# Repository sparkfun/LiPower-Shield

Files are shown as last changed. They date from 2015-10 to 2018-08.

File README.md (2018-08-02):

**NOTE:** *This product has been retired from our catalog. If you are looking for more up-to-date info, please check out some of these resources to see how other users are still hacking and improving on this product.*
* *[SparkFun Forum](https://forum.sparkfun.com/)*
* *[Comments Here on GitHub](https://github.com/sparkfun/LiPower-Shield/issues)*
* *[IRC Channel](https://www.sparkfun.com/news/263)*

SparkFun LiPower Shield
========================

LiPower Shield

[*SparkFun LiPower Shield (DEV-13158)*](https://www.sparkfun.com/products/13158)

This shield allows your Arduino to be powered from a 3.7V LiPo battery, while also charge and monitor the battery. 

Repository Contents
-------------------

* **/Hardware** - All Eagle design files (.brd, .sch)
* **/Production** - Production panel files (.brd)

Product Versions
----------------

* [DEV-13158](https://www.sparkfun.com/products/13158)- Version 1.1. Retired.
* [DEV-10711](https://www.sparkfun.com/products/retired/10711)- Version 1. Retired.

GitHub Version History
---------------
* [Version 1.1](https://github.com/sparkfun/LiPower-Shield/tree/V_1.1) - Latest hardware files. Retired..
* [Version 1](https://github.com/sparkfun/LiPower-Shield/tree/V_1) - Version 1. Retired. 

License Information
-------------------

This product is _**open source**_! 

Please review the LICENSE.md file for license information. 

If you have any questions or concerns on licensing, please contact techsupport@sparkfun.com.

Distributed as-is; no warranty is given.

- Your friends at SparkFun.

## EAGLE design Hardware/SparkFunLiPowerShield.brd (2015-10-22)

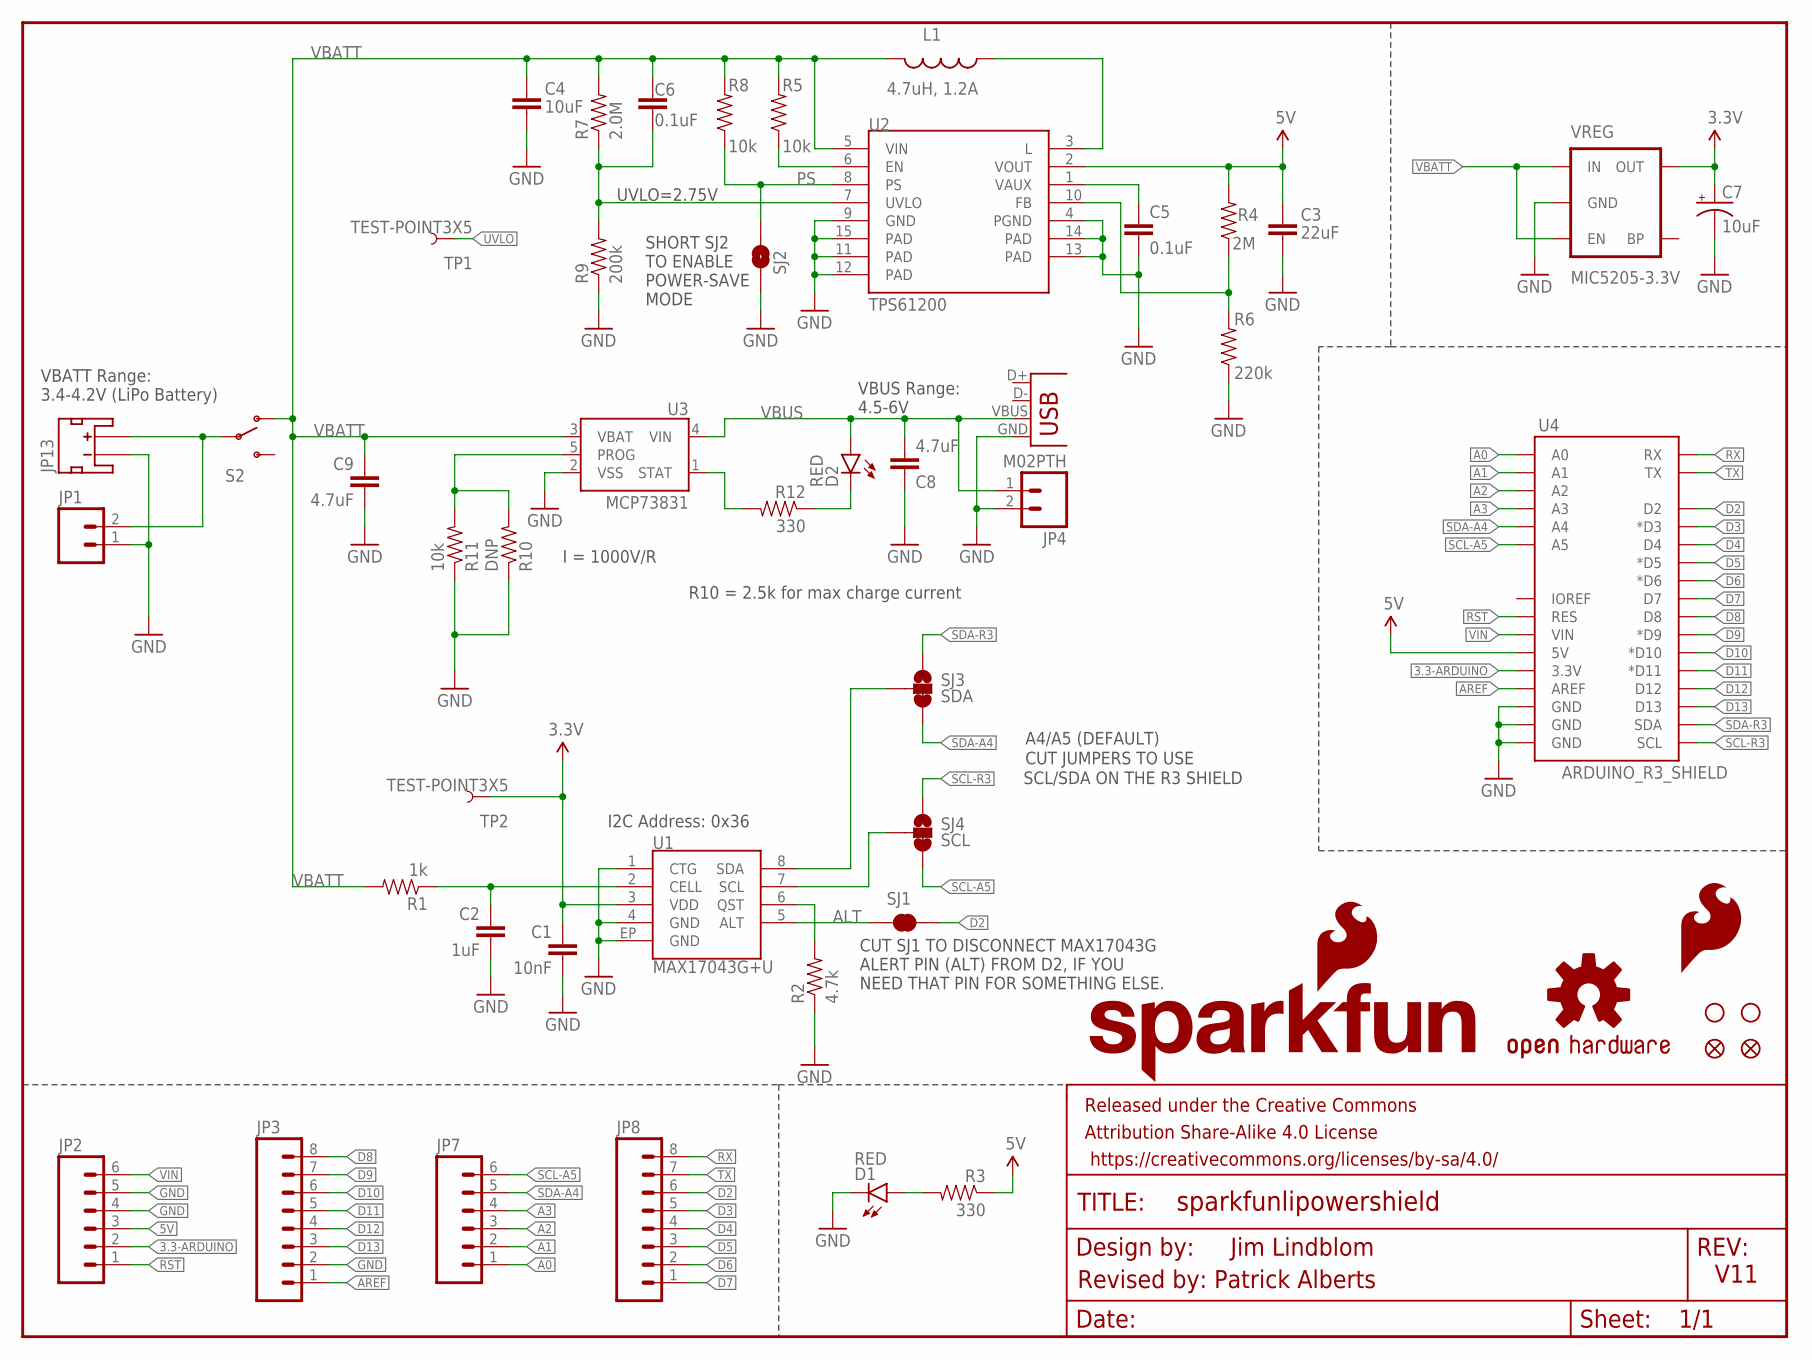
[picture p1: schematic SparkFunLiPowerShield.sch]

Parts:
C1: 10nF; 0603-CAP
C2: 1uF; 0603-CAP
C3: 22uF; 0805
C4: 10uF; 1206
C5, C6: 0.1uF; 0603-CAP
C7: 10uF; EIA3216
C8, C9: 4.7uF; 0603-CAP
D1, D2: RED; LED-0603
FID1, FID2: FIDUCIAL1X2; FIDUCIAL-1X2
FRAME1: FRAME-LETTER; CREATIVE_COMMONS
JP1: M021X02_NO_SILK; 1X02_NO_SILK
JP2, JP7: M06NO_SILK; 1X06_NO_SILK
JP3, JP8: M08NO_SILK; 1X08_NO_SILK
JP4: M02PTH; 1X02
JP9, JP10: STAND-OFFTIGHT; STAND-OFF-TIGHT
JP11: USBSMD; USB-MINIB
JP13: JST_2MM_MALE; JST-2-SMD
L1: 4.7uH, 1.2A; INDUCTOR_4.7UH
LOGO1: OSHW-LOGOS; OSHW-LOGO-S
LOGO2: SFE_LOGO_NAME_FLAME.2_INCH; SFE_LOGO_NAME_FLAME_.2
LOGO3: SFE_LOGO_FLAME.1_INCH; SFE_LOGO_FLAME_.1
R1: 1k; 0603-RES
R2: 4.7k; 0603-RES
R3, R12: 330; 0603-RES
R4: 2M; 0603-RES
R5, R8, R11: 10k; 0603-RES
R6: 220k; 0603-RES
R7: 2.0M; 0603-RES
R9: 200k; 0603-RES
R10: DNP; 1/6W-RES
S2: SWITCH-SPDT-SMD-A; SWITCH-SPST-SMD-A
SJ1: SOLDERJUMPERTRACE; SJ_2S-TRACE
SJ2: PS; SJ_2S-NO
SJ3: SDA; PAD-JUMPER-3-2OF3_NC_BY_TRACE_YES_SILK_FULL_BOX
SJ4: SCL; PAD-JUMPER-3-2OF3_NC_BY_TRACE_YES_SILK_FULL_BOX
TP1, TP2: TEST-POINT3X5; PAD.03X.05
U1: MAX17043G+U; TDFN-8
U2: TPS61200; QFN-10_PAD
U3: MCP73831; SOT23-5
U4: ARDUINO_R3_SHIELD; UNO_R3_SHIELD
VREG: MIC5205-3.3V; SOT23-5

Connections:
3.3-ARDUINO: JP2.2, U4.3.3V
3.3V: C1.1, C7.A (+), TP2.P$1, U1.3 (VDD), VREG.5 (OUT)
5V: C3.1, JP2.3, R3.1, R4.2, U2.2 (VOUT), U4.5V
A0: JP7.1, U4.A0
A1: JP7.2, U4.A1
A2: JP7.3, U4.A2
A3: JP7.4, U4.A3
ALT: SJ1.1, U1.5 (ALT)
AREF: JP3.1, U4.AREF
CELL: C2.1, R1.1, U1.2 (CELL)
D2: JP8.6, SJ1.2, U4.D2
D3: JP8.5, U4.D3 (*D3)
D4: JP8.4, U4.D4
D5: JP8.3, U4.D5 (*D5)
D6: JP8.2, U4.D6 (*D6)
D7: JP8.1, U4.D7
D8: JP3.8, U4.D8
D9: JP3.7, U4.D9 (*D9)
D10: JP3.6, U4.D10 (*D10)
D11: JP3.5, U4.D11 (*D11)
D12: JP3.4, U4.D12
D13: JP3.3, U4.D13
EN: R5.1, U2.6 (EN)
FB: R4.1, R6.2, U2.10 (FB)
GND: C1.2, C2.2, C3.2, C4.2, C5.2, C7.C (-), C8.1, C9.2, D1.C, JP1.1, JP2.4, JP2.5, JP3.2, JP4.2, JP11.GND, JP13.1 (-), R2.1, R6.1, R9.1, R10.1, R11.1, SJ2.1, U1.1 (CTG), U1.4 (GND), U1.EP (GND), U2.4 (PGND), U2.9 (GND), U2.11 (PAD), U2.12 (PAD), U2.13 (PAD), U2.14 (PAD), U2.15 (PAD), U3.2 (VSS), U4.GND@0 (GND), U4.GND@1 (GND), U4.GND@2 (GND), VREG.2 (GND)
unnamed: D1.A, R3.2
unnamed: L1.P$1 (1), U2.3 (L)
unnamed: C5.1, U2.1 (VAUX)
unnamed: D2.C, R12.1
unnamed: JP1.2, JP13.2 (+), S2.2
unnamed: SJ3.2, U1.8 (SDA)
PROG: R10.2, R11.2, U3.5 (PROG)
PS: R8.1, SJ2.2, U2.8 (PS)
QST: R2.2, U1.6 (QST)
RST: JP2.1, U4.RES
RX: JP8.8, U4.RX
SCL: SJ4.2, U1.7 (SCL)
SCL-A5: JP7.6, SJ4.3, U4.A5
SCL-R3: SJ4.1, U4.SCL
SDA-A4: JP7.5, SJ3.3, U4.A4
SDA-R3: SJ3.1, U4.SDA
STAT: R12.2, U3.1 (STAT)
TX: JP8.7, U4.TX
UVLO: C6.2, R7.1, R9.2, TP1.P$1, U2.7 (UVLO)
VBATT: C4.1, C6.1, C9.1, L1.P$2 (2), R1.2, R5.2, R7.2, R8.2, S2.1 (O), U2.5 (VIN), U3.3 (VBAT), VREG.1 (IN), VREG.3 (EN)
VBUS: C8.2, D2.A, JP4.1, JP11.VBUS, U3.4 (VIN)
VIN: JP2.6, U4.VIN

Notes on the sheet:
I = 1000V/R
R10 = 2.5k for max charge current
UVLO=2.75V
V11
Jim Lindblom
Revised by: Patrick Alberts
A4/A5 (DEFAULT)
CUT JUMPERS TO USE
SCL/SDA ON THE R3 SHIELD
SHORT SJ2 TO ENABLE POWER-SAVE MODE
CUT SJ1 TO DISCONNECT MAX17043G ALERT PIN (ALT) FROM D2, IF YOU NEED THAT PIN FOR SOMETHING ELSE.
I2C Address: 0x36
VBATT Range: 3.4-4.2V (LiPo Battery)
VBUS Range: 4.5-6V

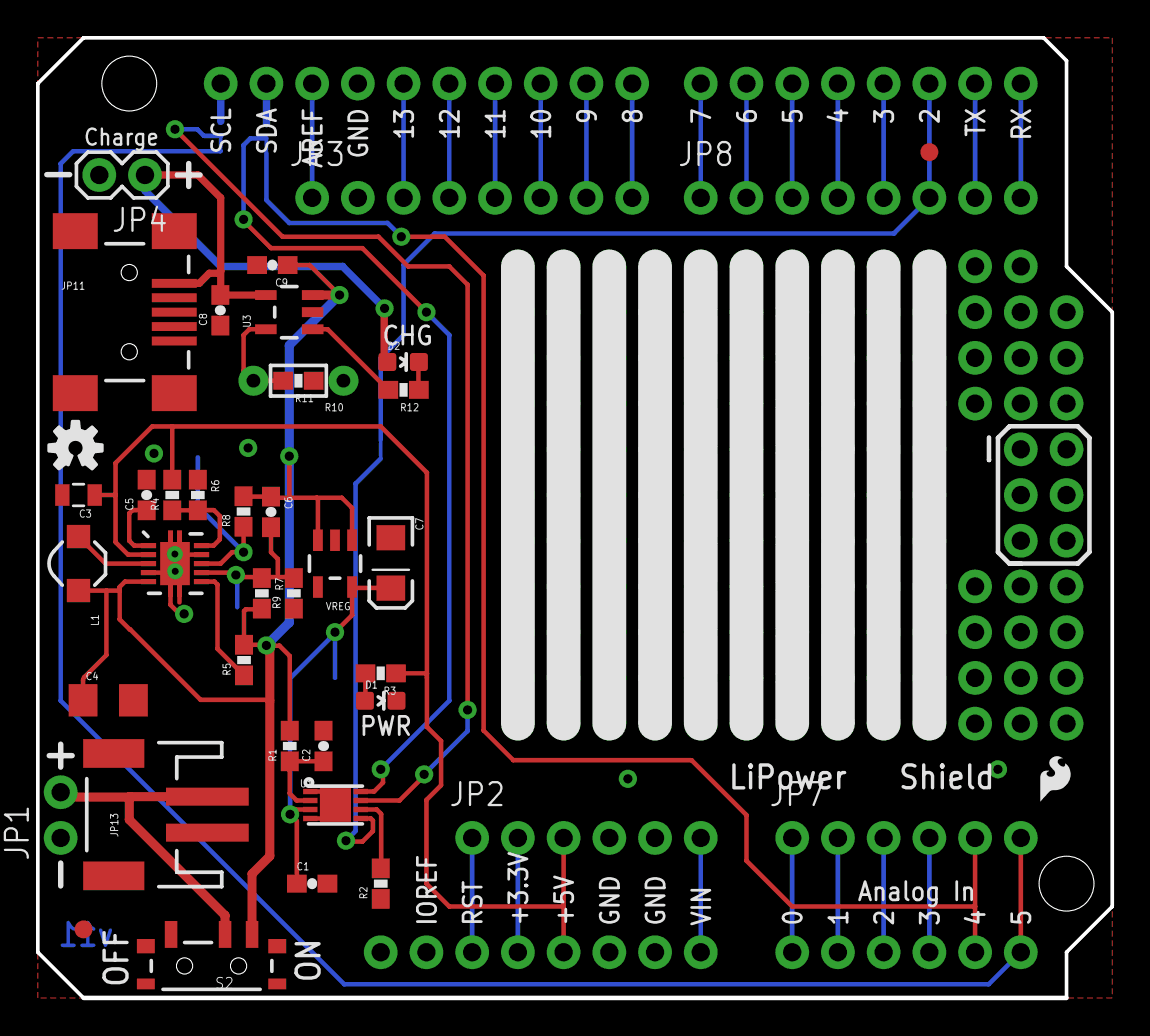
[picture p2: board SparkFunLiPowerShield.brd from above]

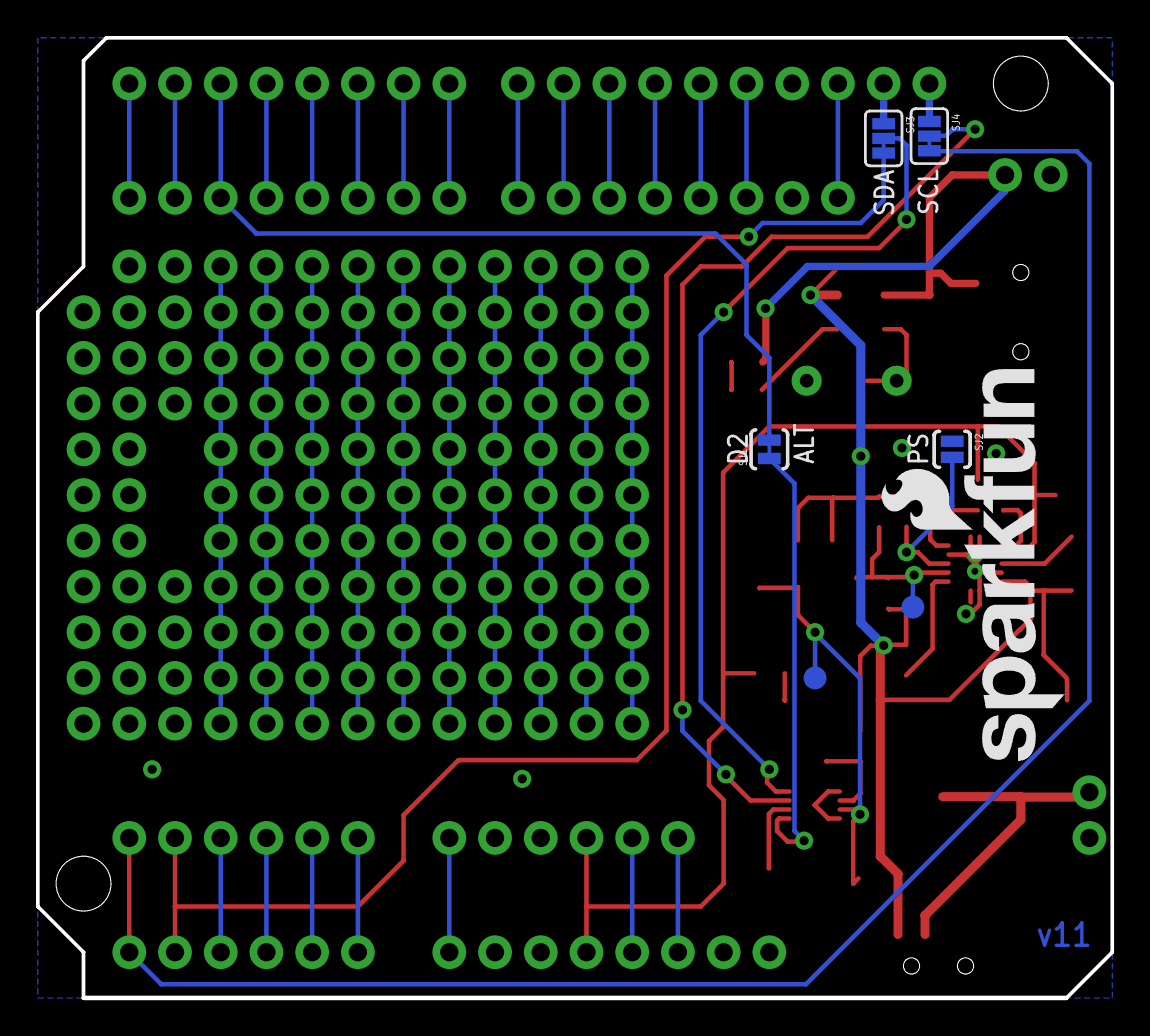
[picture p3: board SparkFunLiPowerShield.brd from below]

Board: 2 copper layers, 59.7 x 53.3 mm, 52 parts (7 on the bottom side), 47 nets.

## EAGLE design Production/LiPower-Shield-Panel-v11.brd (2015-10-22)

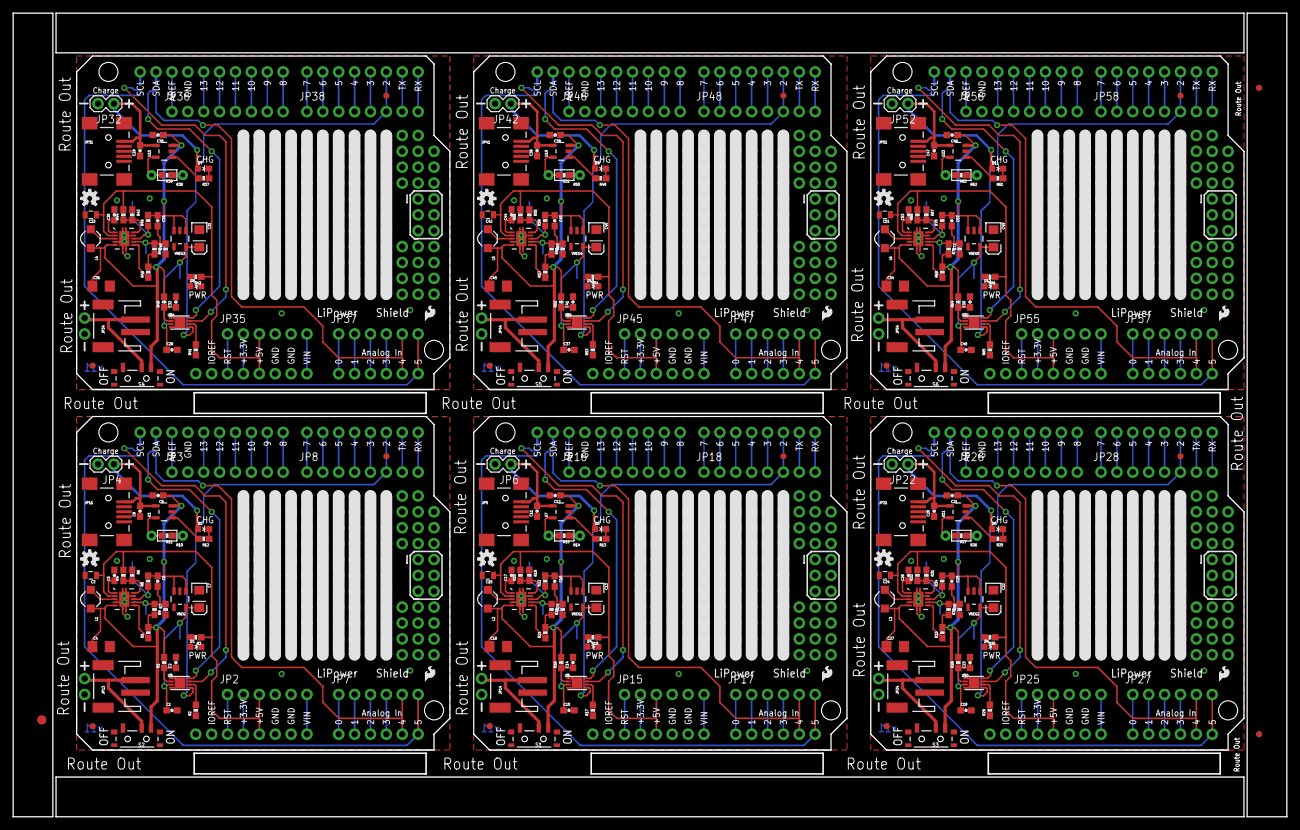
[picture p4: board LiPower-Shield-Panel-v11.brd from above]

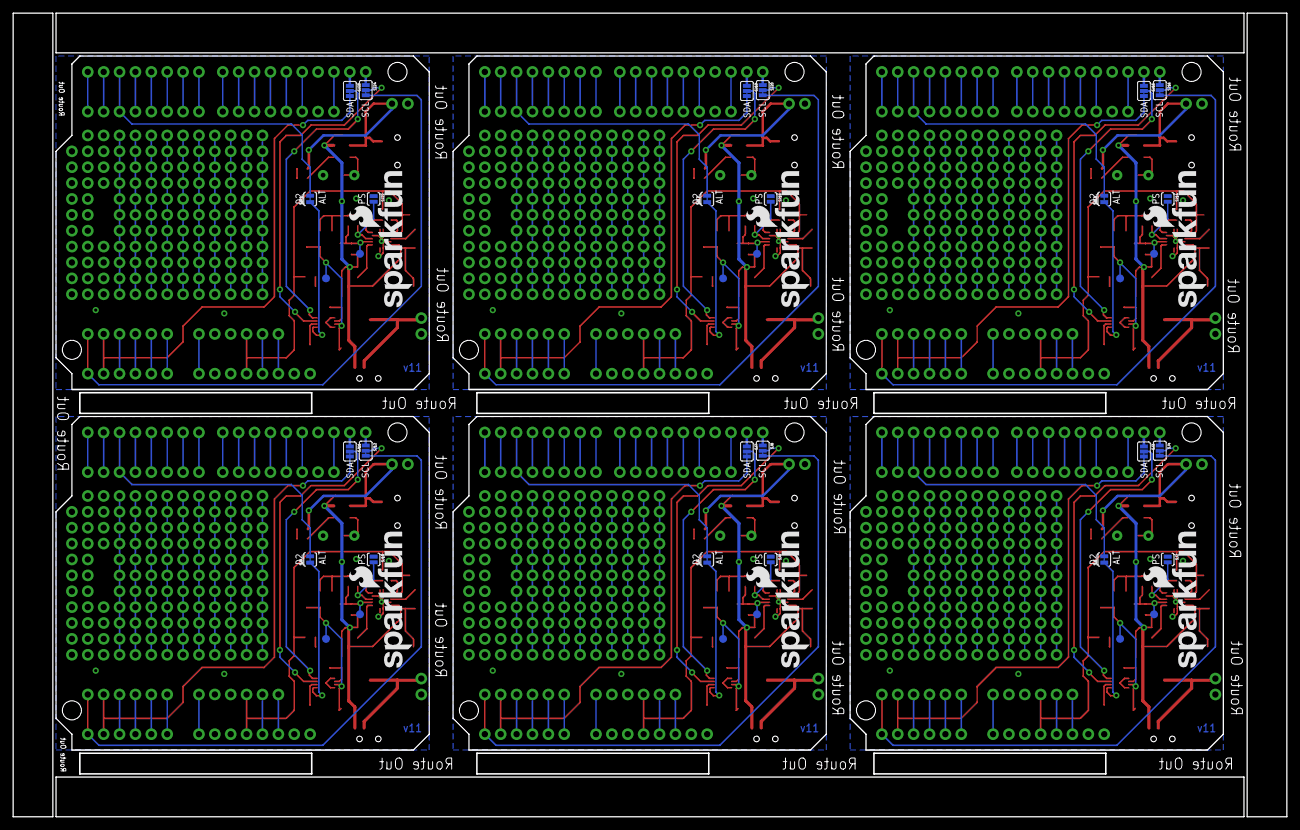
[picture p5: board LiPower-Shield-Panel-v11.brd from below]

Board: 2 copper layers, 203.7 x 128.5 mm, 309 parts (42 on the bottom side), 282 nets.

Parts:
C1, C10, C19, C28, C37, C46: 10nF; 0603-CAP
C2, C14, C23, C32, C41, C50: 1uF; 0603-CAP
C3, C15, C24, C33, C42, C51: 22uF; 0805
C4, C18, C27, C36, C45, C54: 10uF; 1206
C5, C6, C16, C17, C25, C26, C34, C35, C43, C44, C52, C53: 0.1uF; 0603-CAP
C7, C13, C22, C31, C40, C49: 10uF; EIA3216
C8, C9, C11, C12, C20, C21, C29, C30, C38, C39, C47, C48: 4.7uF; 0603-CAP
D1, D2, D3, D4, D5, D6, D7, D8, D9, D10, D11, D12: RED; LED-0603
E$1: FIDUCIAL-1.5X3
E$6, E$7: FIDUCIAL-1X2
FID1, FID2, FID3, FID4, FID5, FID6, FID7, FID8, FID9, FID10, FID11, FID12: FIDUCIAL1X2; FIDUCIAL-1X2
JP1, JP12, JP23, JP33, JP43, JP53: 1X02_NO_SILK
JP2, JP7, JP15, JP17, JP25, JP27, JP35, JP37, JP45, JP47, JP55, JP57: 1X06_NO_SILK
JP3, JP8, JP16, JP18, JP26, JP28, JP36, JP38, JP46, JP48, JP56, JP58: 1X08_NO_SILK
JP4, JP6, JP22, JP32, JP42, JP52: M02PTH; 1X02
JP5, JP11, JP21, JP31, JP41, JP51: USBSMD; USB-MINIB
JP9, JP10, JP19, JP20, JP29, JP30, JP39, JP40, JP49, JP50, JP59, JP60: STAND-OFFTIGHT; STAND-OFF-TIGHT
JP13, JP14, JP24, JP34, JP44, JP54: JST-2-SMD
L1, L2, L3, L4, L5, L6: 4.7uH, 1.2A; INDUCTOR_4.7UH
LOGO1, LOGO4, LOGO7, LOGO10, LOGO13, LOGO16: OSHW-LOGOS; OSHW-LOGO-S
LOGO2, LOGO5, LOGO8, LOGO11, LOGO14, LOGO17: SFE_LOGO_NAME_FLAME.2_INCH; SFE_LOGO_NAME_FLAME_.2
LOGO3, LOGO6, LOGO9, LOGO12, LOGO15, LOGO18: SFE_LOGO_FLAME.1_INCH; SFE_LOGO_FLAME_.1
R1, R16, R28, R40, R52, R64: 1k; 0603-RES
R2, R17, R29, R41, R53, R65: 4.7k; 0603-RES
R3, R12, R13, R18, R25, R30, R37, R42, R49, R54, R61, R66: 330; 0603-RES
R4, R20, R32, R44, R56, R68: 2M; 0603-RES
R5, R8, R11, R15, R21, R22, R27, R33, R34, R39, R45, R46, R51, R57, R58, R63, R69, R70: 10k; 0603-RES
R6, R19, R31, R43, R55, R67: 220k; 0603-RES
R7, R24, R36, R48, R60, R72: 2.0M; 0603-RES
R9, R23, R35, R47, R59, R71: 200k; 0603-RES
R10, R14, R26, R38, R50, R62: DNP; 1/6W-RES
S1, S2, S3, S4, S5, S6: SWITCH-SPST-SMD-A
SJ1, SJ5, SJ9, SJ13, SJ17, SJ21: SOLDERJUMPERTRACE; SJ_2S-TRACE
SJ2, SJ6, SJ10, SJ14, SJ18, SJ22: PS; SJ_2S-NO
SJ3, SJ7, SJ11, SJ15, SJ19, SJ23: SDA; PAD-JUMPER-3-2OF3_NC_BY_TRACE_YES_SILK_FULL_BOX
SJ4, SJ8, SJ12, SJ16, SJ20, SJ24: SCL; PAD-JUMPER-3-2OF3_NC_BY_TRACE_YES_SILK_FULL_BOX
TP1, TP2, TP3, TP4, TP5, TP6, TP7, TP8, TP9, TP10, TP11, TP12: TEST-POINT3X5; PAD.03X.05
U1, U6, U10, U14, U18, U22: MAX17043G+U; TDFN-8
U2, U8, U12, U16, U20, U24: TPS61200; QFN-10_PAD
U3, U7, U11, U15, U19, U23: MCP73831; SOT23-5
U4, U5, U9, U13, U17, U21: ARDUINO_R3_SHIELD; UNO_R3_SHIELD
VREG, VREG1, VREG2, VREG3, VREG4, VREG5: MIC5205-3.3V; SOT23-5

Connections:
3.3-ARDUINO: JP2.2, U4.3.3V
3.3-ARDUINO1: JP15.2, U5.3.3V
3.3-ARDUINO2: JP25.2, U9.3.3V
3.3-ARDUINO3: JP35.2, U13.3.3V
3.3-ARDUINO4: JP45.2, U17.3.3V
3.3-ARDUINO5: JP55.2, U21.3.3V
3.3V: C1.1, C7.A, TP2.P$1, U1.3, VREG.5
3.3V1: C10.1, C13.A, TP4.P$1, U6.3, VREG1.5
3.3V2: C19.1, C22.A, TP6.P$1, U10.3, VREG2.5
3.3V3: C28.1, C31.A, TP8.P$1, U14.3, VREG3.5
3.3V4: C37.1, C40.A, TP10.P$1, U18.3, VREG4.5
3.3V5: C46.1, C49.A, TP12.P$1, U22.3, VREG5.5
5V: C3.1, JP2.3, R3.1, R4.2, U2.2, U4.5V
5V1: C15.1, JP15.3, R18.1, R20.2, U5.5V, U8.2
5V2: C24.1, JP25.3, R30.1, R32.2, U9.5V, U12.2
5V3: C33.1, JP35.3, R42.1, R44.2, U13.5V, U16.2
5V4: C42.1, JP45.3, R54.1, R56.2, U17.5V, U20.2
5V5: C51.1, JP55.3, R66.1, R68.2, U21.5V, U24.2
A0: JP7.1, U4.A0
A1: JP7.2, U4.A1
A2: JP7.3, U4.A2
A3: JP7.4, U4.A3
A4: JP17.4, U5.A3
A5: JP17.3, U5.A2
A6: JP17.2, U5.A1
A7: JP17.1, U5.A0
A8: JP27.4, U9.A3
A9: JP27.3, U9.A2
A10: JP27.2, U9.A1
A11: JP27.1, U9.A0
A12: JP37.4, U13.A3
A13: JP37.3, U13.A2
A14: JP37.2, U13.A1
A15: JP37.1, U13.A0
A16: JP47.4, U17.A3
A17: JP47.3, U17.A2
A18: JP47.2, U17.A1
A19: JP47.1, U17.A0
A20: JP57.4, U21.A3
A21: JP57.3, U21.A2
A22: JP57.2, U21.A1
A23: JP57.1, U21.A0
ALT: SJ1.1, U1.5
ALT1: SJ5.1, U6.5
ALT2: SJ9.1, U10.5
ALT3: SJ13.1, U14.5
ALT4: SJ17.1, U18.5
ALT5: SJ21.1, U22.5
AREF: JP3.1, U4.AREF
AREF1: JP16.1, U5.AREF
AREF2: JP26.1, U9.AREF
AREF3: JP36.1, U13.AREF
AREF4: JP46.1, U17.AREF
AREF5: JP56.1, U21.AREF
CELL: C2.1, R1.1, U1.2
CELL1: C14.1, R16.1, U6.2
CELL2: C23.1, R28.1, U10.2
CELL3: C32.1, R40.1, U14.2
CELL4: C41.1, R52.1, U18.2
CELL5: C50.1, R64.1, U22.2
D1: JP18.5, U5.D3
D2: JP8.6, SJ1.2, U4.D2
D3: JP8.5, U4.D3
D4: JP8.4, U4.D4
D5: JP8.3, U4.D5
D6: JP8.2, U4.D6
D7: JP8.1, U4.D7
D8: JP3.8, U4.D8
D9: JP3.7, U4.D9
D10: JP3.6, U4.D10
D11: JP3.5, U4.D11
D12: JP3.4, U4.D12
D13: JP3.3, U4.D13
D14: JP18.4, U5.D4
D15: JP18.3, U5.D5
D16: JP18.1, U5.D7
D17: JP18.2, U5.D6
D18: JP16.8, U5.D8
D19: JP16.7, U5.D9
D20: JP16.6, U5.D10
D21: JP16.5, U5.D11
D22: JP16.4, U5.D12
D23: JP16.3, U5.D13
D24: JP18.6, SJ5.2, U5.D2
D25: JP28.5, U9.D3
D26: JP28.4, U9.D4
D27: JP28.3, U9.D5
D28: JP28.1, U9.D7
D29: JP28.2, U9.D6
D30: JP26.8, U9.D8
D31: JP26.7, U9.D9
D32: JP26.6, U9.D10
D33: JP26.5, U9.D11
D34: JP26.4, U9.D12
D35: JP26.3, U9.D13
D36: JP28.6, SJ9.2, U9.D2
D37: JP38.5, U13.D3
D38: JP38.4, U13.D4
D39: JP38.3, U13.D5
D40: JP38.1, U13.D7
D41: JP38.2, U13.D6
D42: JP36.8, U13.D8
D43: JP36.7, U13.D9
D44: JP36.6, U13.D10
D45: JP36.5, U13.D11
D46: JP36.4, U13.D12
D47: JP36.3, U13.D13
D48: JP38.6, SJ13.2, U13.D2
D49: JP48.5, U17.D3
D50: JP48.4, U17.D4
D51: JP48.3, U17.D5
D52: JP48.1, U17.D7
D53: JP48.2, U17.D6
D54: JP46.8, U17.D8
D55: JP46.7, U17.D9
D56: JP46.6, U17.D10
D57: JP46.5, U17.D11
D58: JP46.4, U17.D12
D59: JP46.3, U17.D13
D60: JP48.6, SJ17.2, U17.D2
D61: JP58.5, U21.D3
D62: JP58.4, U21.D4
D63: JP58.3, U21.D5
D64: JP58.1, U21.D7
D65: JP58.2, U21.D6
D66: JP56.8, U21.D8
D67: JP56.7, U21.D9
D68: JP56.6, U21.D10
D69: JP56.5, U21.D11
D70: JP56.4, U21.D12
D71: JP56.3, U21.D13
D72: JP58.6, SJ21.2, U21.D2
EN: R5.1, U2.6
EN1: R21.1, U8.6
EN2: R33.1, U12.6
EN3: R45.1, U16.6
EN4: R57.1, U20.6
EN5: R69.1, U24.6
FB: R4.1, R6.2, U2.10
FB1: R19.2, R20.1, U8.10
FB2: R31.2, R32.1, U12.10
FB3: R43.2, R44.1, U16.10
FB4: R55.2, R56.1, U20.10
FB5: R67.2, R68.1, U24.10
GND: C1.2, C2.2, C3.2, C4.2, C5.2, C7.C, C8.1, C9.2, D1.C, JP1.1, JP2.4, JP2.5, JP3.2, JP4.2, JP11.GND, JP13.1, R2.1, R6.1, R9.1, R10.1, R11.1, SJ2.1, U1.1, U1.4, U1.EP, U2.4, U2.9, U2.11, U2.12, U2.13, U2.14, U2.15, U3.2, U4.GND@0, U4.GND@1, U4.GND@2, VREG.2
GND1: C10.2, C11.1, C12.2, C13.C, C14.2, C15.2, C17.2, C18.2, D4.C, JP5.GND, JP6.2, JP12.1, JP14.1, JP15.4, JP15.5, JP16.2, R14.1, R15.1, R17.1, R19.1, R23.1, SJ6.1, U5.GND@0, U5.GND@1, U5.GND@2, U6.1, U6.4, U6.EP, U7.2, U8.4, U8.9, U8.11, U8.12, U8.13, U8.14, U8.15, VREG1.2
GND2: C19.2, C20.1, C21.2, C22.C, C23.2, C24.2, C26.2, C27.2, D6.C, JP21.GND, JP22.2, JP23.1, JP24.1, JP25.4, JP25.5, JP26.2, R26.1, R27.1, R29.1, R31.1, R35.1, SJ10.1, U9.GND@0, U9.GND@1, U9.GND@2, U10.1, U10.4, U10.EP, U11.2, U12.4, U12.9, U12.11, U12.12, U12.13, U12.14, U12.15, VREG2.2
GND3: C28.2, C29.1, C30.2, C31.C, C32.2, C33.2, C35.2, C36.2, D8.C, JP31.GND, JP32.2, JP33.1, JP34.1, JP35.4, JP35.5, JP36.2, R38.1, R39.1, R41.1, R43.1, R47.1, SJ14.1, U13.GND@0, U13.GND@1, U13.GND@2, U14.1, U14.4, U14.EP, U15.2, U16.4, U16.9, U16.11, U16.12, U16.13, U16.14, U16.15, VREG3.2
GND4: C37.2, C38.1, C39.2, C40.C, C41.2, C42.2, C44.2, C45.2, D10.C, JP41.GND, JP42.2, JP43.1, JP44.1, JP45.4, JP45.5, JP46.2, R50.1, R51.1, R53.1, R55.1, R59.1, SJ18.1, U17.GND@0, U17.GND@1, U17.GND@2, U18.1, U18.4, U18.EP, U19.2, U20.4, U20.9, U20.11, U20.12, U20.13, U20.14, U20.15, VREG4.2
GND5: C46.2, C47.1, C48.2, C49.C, C50.2, C51.2, C53.2, C54.2, D12.C, JP51.GND, JP52.2, JP53.1, JP54.1, JP55.4, JP55.5, JP56.2, R62.1, R63.1, R65.1, R67.1, R71.1, SJ22.1, U21.GND@0, U21.GND@1, U21.GND@2, U22.1, U22.4, U22.EP, U23.2, U24.4, U24.9, U24.11, U24.12, U24.13, U24.14, U24.15, VREG5.2
unnamed: D1.A, R3.2
unnamed: L1.P$1, U2.3
unnamed: C5.1, U2.1
unnamed: D2.C, R12.1
unnamed: JP1.2, JP13.2, S2.2
unnamed: SJ3.2, U1.8
unnamed: D3.C, R13.1
unnamed: SJ7.2, U6.8
unnamed: D4.A, R18.2
unnamed: L2.P$1, U8.3
unnamed: C17.1, U8.1
unnamed: JP12.2, JP14.2, S1.2
unnamed: D5.C, R25.1
unnamed: SJ11.2, U10.8
unnamed: D6.A, R30.2
unnamed: L3.P$1, U12.3
unnamed: C26.1, U12.1
unnamed: JP23.2, JP24.2, S3.2
unnamed: D7.C, R37.1
unnamed: SJ15.2, U14.8
unnamed: D8.A, R42.2
unnamed: L4.P$1, U16.3
unnamed: C35.1, U16.1
unnamed: JP33.2, JP34.2, S4.2
unnamed: D9.C, R49.1
unnamed: SJ19.2, U18.8
unnamed: D10.A, R54.2
unnamed: L5.P$1, U20.3
unnamed: C44.1, U20.1
unnamed: JP43.2, JP44.2, S5.2
unnamed: D11.C, R61.1
unnamed: SJ23.2, U22.8
unnamed: D12.A, R66.2
unnamed: L6.P$1, U24.3
unnamed: C53.1, U24.1
unnamed: JP53.2, JP54.2, S6.2
PROG: R10.2, R11.2, U3.5
PROG1: R14.2, R15.2, U7.5
PROG2: R26.2, R27.2, U11.5
PROG3: R38.2, R39.2, U15.5
PROG4: R50.2, R51.2, U19.5
PROG5: R62.2, R63.2, U23.5
PS: R8.1, SJ2.2, U2.8
PS1: R22.1, SJ6.2, U8.8
PS2: R34.1, SJ10.2, U12.8
PS3: R46.1, SJ14.2, U16.8
PS4: R58.1, SJ18.2, U20.8
PS5: R70.1, SJ22.2, U24.8
QST: R2.2, U1.6
QST1: R17.2, U6.6
QST2: R29.2, U10.6
QST3: R41.2, U14.6
QST4: R53.2, U18.6
QST5: R65.2, U22.6
RST: JP2.1, U4.RES
RST1: JP15.1, U5.RES
RST2: JP25.1, U9.RES
RST3: JP35.1, U13.RES
RST4: JP45.1, U17.RES
RST5: JP55.1, U21.RES
RX: JP8.8, U4.RX
RX1: JP18.8, U5.RX
RX2: JP28.8, U9.RX
RX3: JP38.8, U13.RX
RX4: JP48.8, U17.RX
RX5: JP58.8, U21.RX
SCL: SJ4.2, U1.7
SCL1: SJ8.2, U6.7
SCL2: SJ12.2, U10.7
SCL3: SJ16.2, U14.7
SCL4: SJ20.2, U18.7
SCL5: SJ24.2, U22.7
SCL-A1: JP17.6, SJ8.3, U5.A5
SCL-A2: JP27.6, SJ12.3, U9.A5
SCL-A3: JP37.6, SJ16.3, U13.A5
SCL-A4: JP47.6, SJ20.3, U17.A5
SCL-A5: JP7.6, SJ4.3, U4.A5
SCL-A6: JP57.6, SJ24.3, U21.A5
SCL-R1: SJ8.1, U5.SCL
SCL-R2: SJ12.1, U9.SCL
SCL-R3: SJ4.1, U4.SCL
SCL-R4: SJ16.1, U13.SCL
SCL-R5: SJ20.1, U17.SCL
SCL-R6: SJ24.1, U21.SCL
SDA-A1: JP17.5, SJ7.3, U5.A4
SDA-A2: JP27.5, SJ11.3, U9.A4
SDA-A3: JP37.5, SJ15.3, U13.A4
SDA-A4: JP7.5, SJ3.3, U4.A4
SDA-A5: JP47.5, SJ19.3, U17.A4
SDA-A6: JP57.5, SJ23.3, U21.A4
SDA-R1: SJ7.1, U5.SDA
SDA-R2: SJ11.1, U9.SDA
SDA-R3: SJ3.1, U4.SDA
SDA-R4: SJ15.1, U13.SDA
SDA-R5: SJ19.1, U17.SDA
SDA-R6: SJ23.1, U21.SDA
STAT: R12.2, U3.1
STAT1: R13.2, U7.1
STAT2: R25.2, U11.1
STAT3: R37.2, U15.1
STAT4: R49.2, U19.1
STAT5: R61.2, U23.1
TX: JP8.7, U4.TX
TX1: JP18.7, U5.TX
TX2: JP28.7, U9.TX
TX3: JP38.7, U13.TX
TX4: JP48.7, U17.TX
TX5: JP58.7, U21.TX
UVLO: C6.2, R7.1, R9.2, TP1.P$1, U2.7
UVLO1: C16.2, R23.2, R24.1, TP3.P$1, U8.7
UVLO2: C25.2, R35.2, R36.1, TP5.P$1, U12.7
UVLO3: C34.2, R47.2, R48.1, TP7.P$1, U16.7
UVLO4: C43.2, R59.2, R60.1, TP9.P$1, U20.7
UVLO5: C52.2, R71.2, R72.1, TP11.P$1, U24.7
VBATT: C4.1, C6.1, C9.1, L1.P$2, R1.2, R5.2, R7.2, R8.2, S2.1, U2.5, U3.3, VREG.1, VREG.3
VBATT1: C12.1, C16.1, C18.1, L2.P$2, R16.2, R21.2, R22.2, R24.2, S1.1, U7.3, U8.5, VREG1.1, VREG1.3
VBATT2: C21.1, C25.1, C27.1, L3.P$2, R28.2, R33.2, R34.2, R36.2, S3.1, U11.3, U12.5, VREG2.1, VREG2.3
VBATT3: C30.1, C34.1, C36.1, L4.P$2, R40.2, R45.2, R46.2, R48.2, S4.1, U15.3, U16.5, VREG3.1, VREG3.3
VBATT4: C39.1, C43.1, C45.1, L5.P$2, R52.2, R57.2, R58.2, R60.2, S5.1, U19.3, U20.5, VREG4.1, VREG4.3
VBATT5: C48.1, C52.1, C54.1, L6.P$2, R64.2, R69.2, R70.2, R72.2, S6.1, U23.3, U24.5, VREG5.1, VREG5.3
VBUS: C8.2, D2.A, JP4.1, JP11.VBUS, U3.4
VBUS1: C11.2, D3.A, JP5.VBUS, JP6.1, U7.4
VBUS2: C20.2, D5.A, JP21.VBUS, JP22.1, U11.4
VBUS3: C29.2, D7.A, JP31.VBUS, JP32.1, U15.4
VBUS4: C38.2, D9.A, JP41.VBUS, JP42.1, U19.4
VBUS5: C47.2, D11.A, JP51.VBUS, JP52.1, U23.4
VIN: JP2.6, U4.VIN
VIN1: JP15.6, U5.VIN
VIN2: JP25.6, U9.VIN
VIN3: JP35.6, U13.VIN
VIN4: JP45.6, U17.VIN
VIN5: JP55.6, U21.VIN

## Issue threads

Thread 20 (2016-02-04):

update eagle files to reflect production DNP of power led

lewispg228, 2016-02-04:

ToniCorinne, 2017-02-08:
Revision is live. Closing this out as resolved.

Closed 2017-02-08.

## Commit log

2013-09-11 Initial Commit
    -gitignore
    -brd
    -sch
    [LiPower-Shield.brd, LiPower-Shield.sch]
2013-09-11 Had to re-commit original files
    The v13 files that I pulled from the network are not what we have on
    storefront. commited v12, also from the network, seems to be the same
    as the SF product.
    [LiPower-Shield.brd, LiPower-Shield.sch]
2014-06-13 Computer Change
    0603 updated, r3 update. JST update, trace rework and schematic
    cleanup.
    [LiPower-Shield.brd, LiPower-Shield.sch]
2014-06-26 re-up
    Re Committed the original files.
    [LiPower-Shield.brd]
2014-08-18 Added OSHW, SPK Logo
    Also added flags to schematic
    [LiPower-Shield.brd, LiPower-Shield.sch]
2014-08-18 Computer Change
    [LiPower-Shield.brd]
2014-10-06 Added jumpers, isolated isp headers, trace reroutes
    Added SCL SDA jumpers
    Thermal relief for ground headers as well as changing all vias to
    headers.
    Added Test point for qc
    [LiPower-Shield.brd, LiPower-Shield.sch]
2014-10-07 added dimension line, removed silk on proto headers
    [LiPower-Shield.brd]
2014-11-12 Changed res values on the UVLO line.
    [LiPower-Shield.brd, LiPower-Shield.sch]
2014-11-12 Changed UVLO voltage in SCH
    [LiPower-Shield.sch]
2014-11-14 Moved Sparkfun silk
    [LiPower-Shield.brd]
2014-11-18 Changed r7 back to 2m
    [LiPower-Shield.brd, LiPower-Shield.sch]
2014-11-20 Added test point, Lines around Sch parts and Prod Att
    [LiPower-Shield.brd, LiPower-Shield.sch]
2014-11-20 Added info on SDA/SCL jumpers
    [LiPower-Shield.sch]
2014-11-20 Adding descriptions to SJ1 and SJ2.
    [LiPower-Shield.sch]
2014-11-21 Reduced paste on IC's
    [LiPower-Shield.brd, LiPower-Shield.sch]
2014-11-21 Adding MAX17043G I2C address to schematic.
    [LiPower-Shield.sch]
2014-11-21 Adding voltage input range notes.
    [LiPower-Shield.sch]
2014-11-21 Added prod id's for nduc/caps
    [LiPower-Shield.brd, LiPower-Shield.sch]
2014-11-21 Updated paste on IC's
    [LiPower-Shield.brd, LiPower-Shield.sch]
2014-11-21 Schematic Cleanup
    fixed all of these...
    1) GND and 5V symbols need to be rotated "up" and "down".
    2) all LEDs prefixes should be "D#"
    3) R4 needs to be shifted down one grid space. The resulting 4 way
    junction will need to be fixed then too.
    4) J1 should have a prefix of JP#
    5) USB connector is currently "X1" should be a JP prefix.
    6) small flame symbol needs to be updated.
    [LiPower-Shield.brd, LiPower-Shield.sch]
2014-11-24 changed fids to regular from micro
    [LiPower-Shield.brd, LiPower-Shield.sch]
2014-12-09 Fixed current QC checklist issues.
    [LiPower-Shield.brd, LiPower-Shield.sch]
2014-12-10 Moved net on LED
    [LiPower-Shield.brd, LiPower-Shield.sch]
2015-01-12 created panel v11
    [LiPower-Shield-Panel-v11.brd]
2015-10-22 Updating README with new product info, adding License file
    [LiPower-Shield-Panel-v11.brd]
2018-08-02 Hardware Folder Issues
    Weird GitHub display Issue with Hardware folder. Removing directory.
    [SparkFunLiPowerShield.brd, SparkFunLiPowerShield.sch]
2018-08-02 New Hardware Folder
    Weird issue where it was displaying eagle files two separate folders: HARDWARE and Hardware.
    [SparkFunLiPowerShield.brd, SparkFunLiPowerShield.sch]

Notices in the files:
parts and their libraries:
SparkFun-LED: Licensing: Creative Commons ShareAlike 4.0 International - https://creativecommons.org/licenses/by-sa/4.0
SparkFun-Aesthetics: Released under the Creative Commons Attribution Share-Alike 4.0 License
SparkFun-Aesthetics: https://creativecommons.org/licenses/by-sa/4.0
